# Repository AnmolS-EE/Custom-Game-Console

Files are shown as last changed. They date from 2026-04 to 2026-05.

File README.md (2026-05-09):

# Custom ESP32 Arcade Console (V1.0)

An arcade-style game console built around the ESP32 microcontroller featuring a custom 2-layer PCB, OLED display, joystick input, tactile buttons, buzzer feedback, and multi-color LED's.

## Hardware Features
* **Microcontroller:** ESP32-WROOM-32
* **Display:** 0.96" I2C OLED Display
* **Controls:** 2-axis analog joystick + 4 tactile push buttons
* **Feedback:** Active buzzer for game audio + 4 status LEDs
* **Power:** Custom 2-layer PCB designed in KiCad

### Schematic
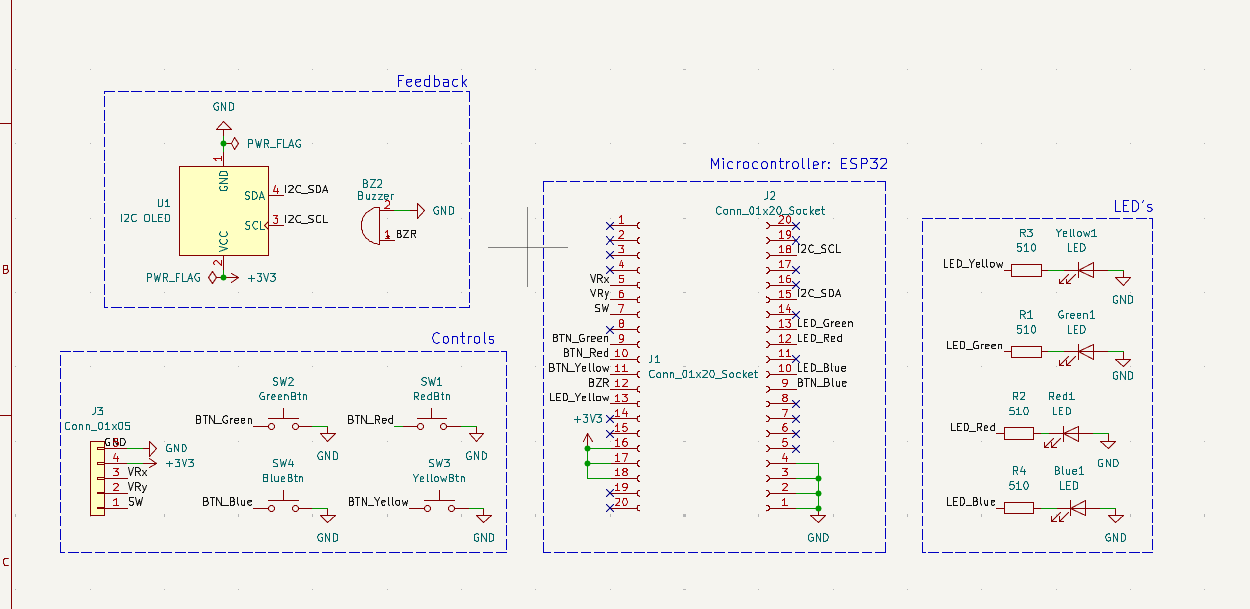
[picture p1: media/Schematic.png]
Circuit Schematic


### 3D PCB View
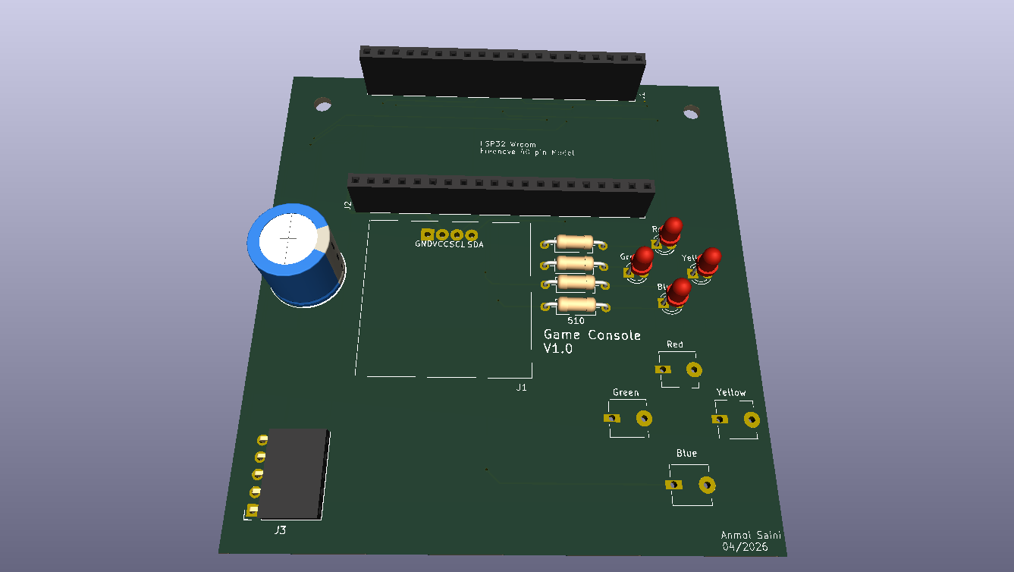
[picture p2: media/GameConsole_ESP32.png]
3D PCB View


## Project Evolution: Breadboard to PCB
The project began as a fully functional breadboard prototype used to validate:

* GPIO pin mapping
* joystick input behavior
* display communication (I2C)
* game state transitions
* buzzer and LED feedback logic

### Breadboard Prototype
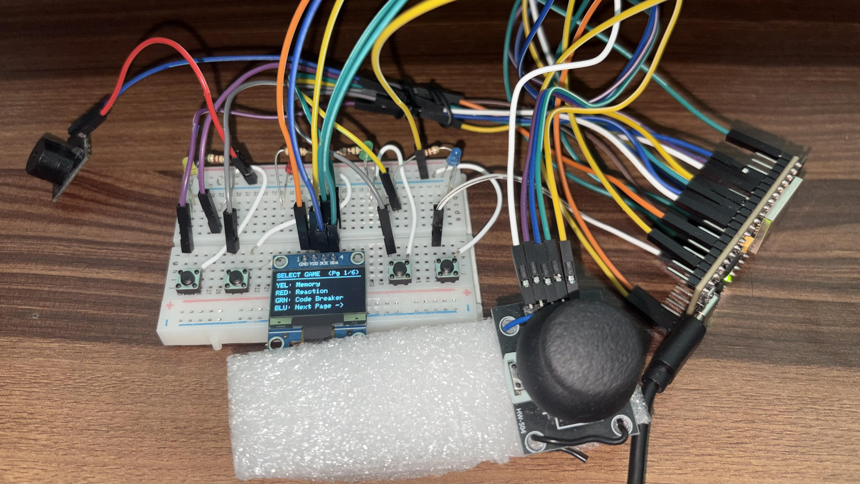
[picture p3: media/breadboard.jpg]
Breadboard Prototype
]

After successful testing, the system was transferred to a custom PCB designed in KiCad, focusing on clean signal routing, reliable power delivery, and compact system integration. 

### Assembled Hardware
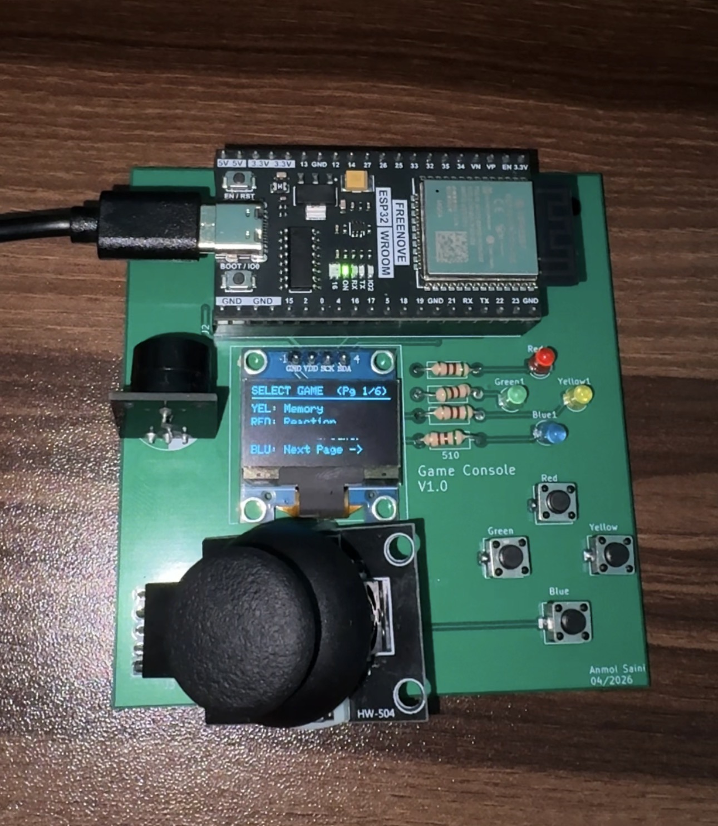
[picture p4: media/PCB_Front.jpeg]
Fully Assembled PCB


The final manufactured board has been created and the components have been soldered on. This transformed the initial breadboard concept into a robust, standalone device. You can watch a small edit of the soldering and final assembly process in my [TikTok build video](https://www.tiktok.com/@anmol.ee/video/7637941595454639381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).

## Firmware & Logic
Firmware was developed using C++ (Arduino IDE) on the ESP32 development board.
The software architecture supports multiple programmable games with modular input handling, display rendering, state management, and sound feedback.

## Future Improvements (V2.0)
While version 1.0 successfully validates the core hardware and software architecture, future versions will focus on a more clean and consumer-ready design. Planned improvements include:

* **Component Integration:** Transitioning away from bulky pre-packaged modules by designing custom footprints to mount a bare joystick and buzzer directly onto the PCB.
* **Enhanced Display:** Upgrading to a larger OLED screen for improved visibility and addition of color.
* **Layout Optimization:** Refining the PCB trace routing and component placement for an even cleaner and more efficient board design.
* **Custom Enclosure:** Designing and 3D printing a custom case to house the console, improve handling, and protect the exposed circuitry.

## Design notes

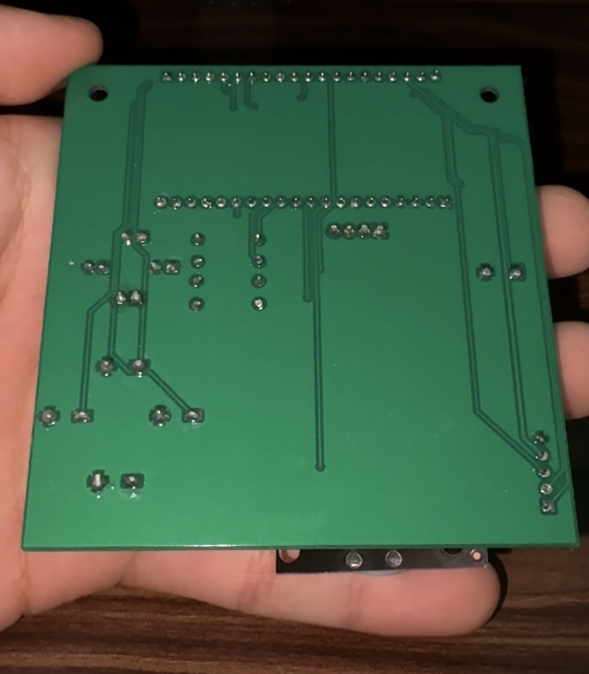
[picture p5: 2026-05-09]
media/PCB_Back.jpeg

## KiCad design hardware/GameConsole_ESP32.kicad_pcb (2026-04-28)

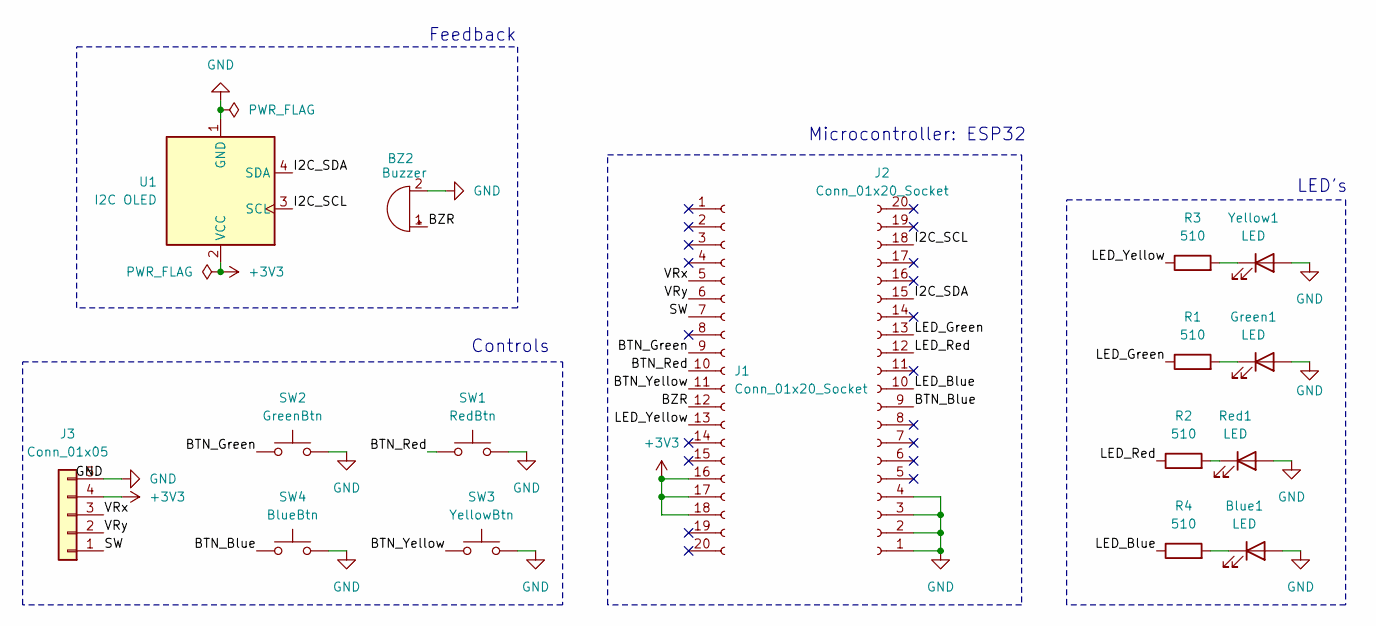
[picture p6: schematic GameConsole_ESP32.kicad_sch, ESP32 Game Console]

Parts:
BZ2: Buzzer; CP_Radial_D12.5mm_P5.00mm
Blue1: LED; LED_D3.0mm
Green1: LED; LED_D3.0mm
J1, J2: Conn_01x20_Socket; PinSocket_1x20_P2.54mm_Vertical
J3: Conn_01x05; PinSocket_1x05_P2.54mm_Horizontal
R1, R2, R3, R4: 510; R_Axial_DIN0207_L6.3mm_D2.5mm_P10.16mm_Horizontal
Red1: LED; LED_D3.0mm
SW1: RedBtn; SW_PUSH_6x6mm_2Pin_P5.08mm
SW2: GreenBtn; SW_PUSH_6x6mm_2Pin_P5.08mm
SW3: YellowBtn; SW_PUSH_6x6mm_2Pin_P5.08mm
SW4: BlueBtn; SW_PUSH_6x6mm_2Pin_P5.08mm
U1: I2C OLED; miniOLED
Yellow1: LED; LED_D3.0mm

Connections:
+3V3: J1.16, J1.17, J1.18, J3.4, U1.2 (VCC)
/BTN_Blue: J2.9, SW4.1
/BTN_Green: J1.9, SW2.1
/BTN_Red: J1.10, SW1.1
/BTN_Yellow: J1.11, SW3.1
/BZR: BZ2.1 (+), J1.12
/I2C_SCL: J2.18, U1.3 (SCL)
/I2C_SDA: J2.15, U1.4 (SDA)
/LED_Blue: J2.10, R4.1
/LED_Green: J2.13, R1.1
/LED_Red: J2.12, R2.1
/LED_Yellow: J1.13, R3.1
/SW: J1.7, J3.1
/VRx: J1.5, J3.3
/VRy: J1.6, J3.2
GND: BZ2.2 (-), Blue1.2 (A), Green1.2 (A), J2.1, J2.2, J2.3, J2.4, J3.5, Red1.2 (A), SW1.2, SW2.2, SW3.2, SW4.2, U1.1 (GND), Yellow1.2 (A)
unnamed: Blue1.1 (K), R4.2
unnamed: Green1.1 (K), R1.2
unnamed: R2.2, Red1.1 (K)
unnamed: R3.2, Yellow1.1 (K)

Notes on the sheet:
Microcontroller: ESP32
LED's
Controls
Feedback

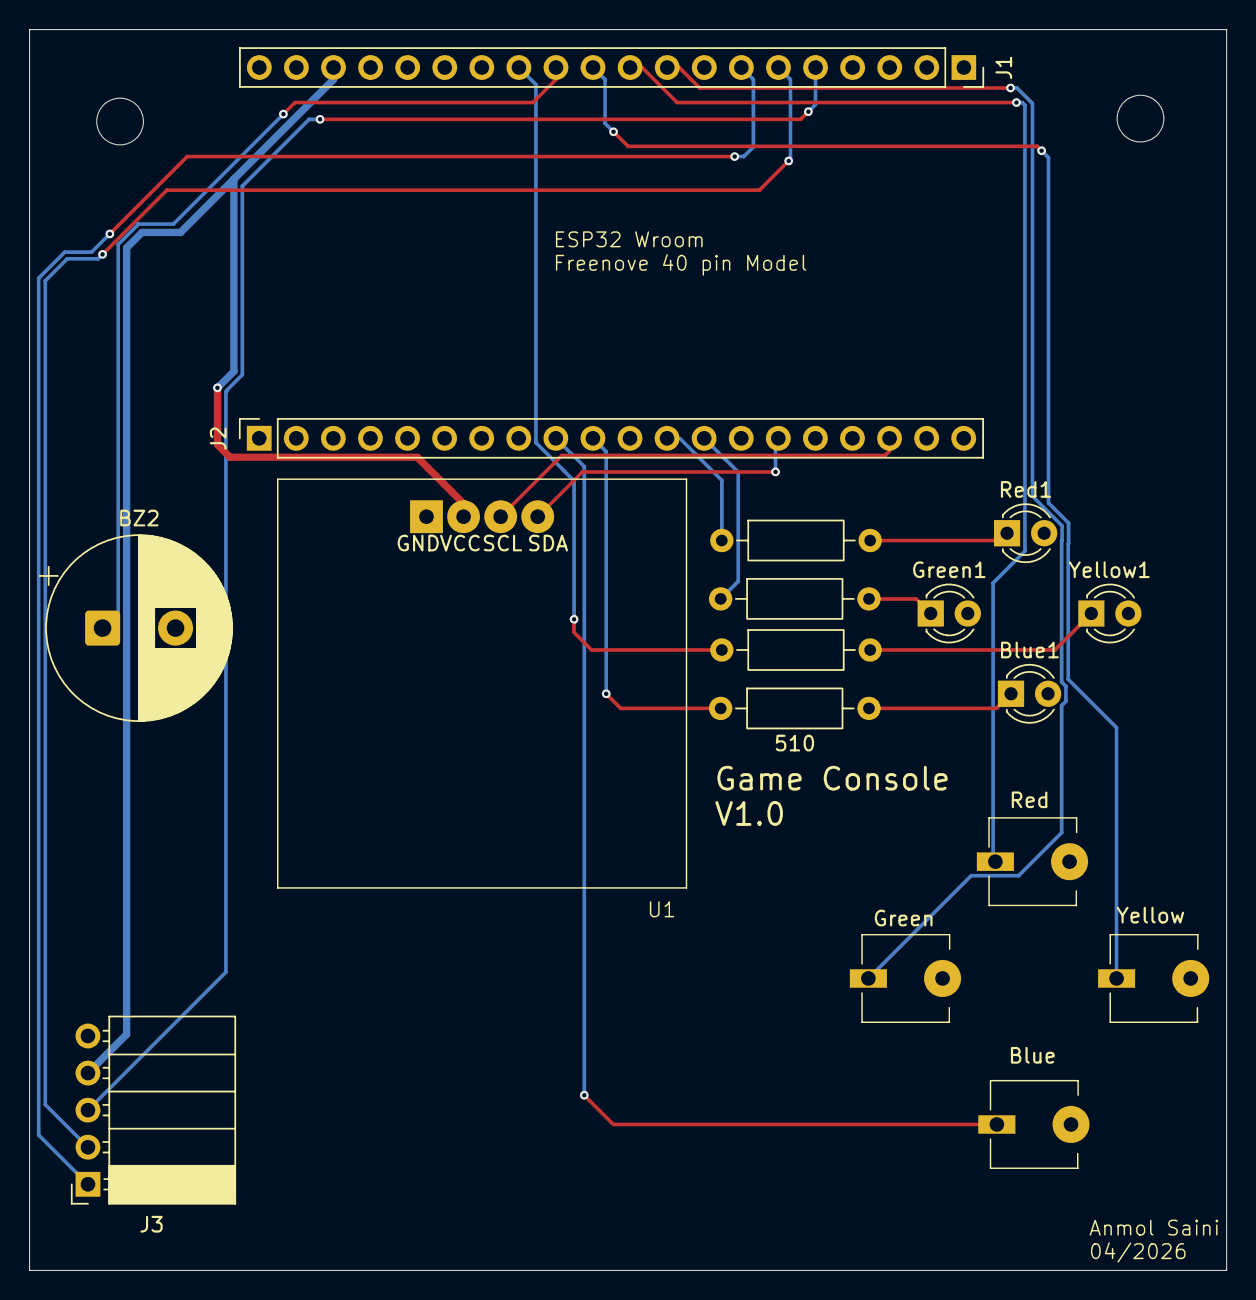
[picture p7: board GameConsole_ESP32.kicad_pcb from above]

Board: 2 copper layers, 82.0 x 85.0 mm, 17 parts (0 on the bottom side), 20 nets.

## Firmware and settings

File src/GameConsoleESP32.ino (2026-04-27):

#include <Wire.h>
#include <Adafruit_GFX.h>
#include <Adafruit_SSD1306.h>
#include <Preferences.h>

#define SCREEN_WIDTH 128 
#define SCREEN_HEIGHT 64 
Adafruit_SSD1306 display(SCREEN_WIDTH, SCREEN_HEIGHT, &Wire, -1);


Preferences preferences;


int leds[] = {13, 18, 19, 17};   // 0:Yellow, 1:Red, 2:Green, 3:Blue
int btns[] = {27, 26, 25, 16};   // Coressponding buttons
int buzzer = 14;              

// Game State Machine
enum GameState {
  MENU,
  MEM_START, REACT_START, CODE_START, CATCH_START, 
  LIGHTS_START, CIRCUIT_START, TWENTYONE_START,
  TRADER_START, DINO_START, WHACK_START, LUNAR_START, 
  SNAKE_START, MAZE_START, ASTEROID_START, SKY_START, CAVE_START
};
GameState currentState = MENU;

// Menu Pagination
int menuPage = 0; // 0 = Pg 1, 1 = Pg 2, 2 = Pg 3, 3 = Pg 4, 4 = Pg 5

// Global Game Variables
int gameSequence[50];            
int level = 2;                   

void setup() {
  Serial.begin(115200);
  if(!display.begin(SSD1306_SWITCHCAPVCC, 0x3C)) { for(;;); }

  for(int i=0; i<4; i++) {
    pinMode(leds[i], OUTPUT);
    pinMode(btns[i], INPUT_PULLUP);
  }
  pinMode(buzzer, OUTPUT);
  digitalWrite(buzzer, LOW);
  randomSeed(analogRead(0));
}

void loop() {
  switch (currentState) {
    case MENU: {
      showMenu();
      int btnPressed = waitForButton();
      
      if (btnPressed == 3) { // Blue button scrolls pages
        menuPage++;
        if (menuPage > 5) menuPage = 0;
        delay(200); 
      }
      else if (menuPage == 0) {
        if (btnPressed == 0) currentState = MEM_START;
        else if (btnPressed == 1) currentState = REACT_START;
        else if (btnPressed == 2) currentState = CODE_START;
      }
      else if (menuPage == 1) {
        if (btnPressed == 0) currentState = CATCH_START;
        else if (btnPressed == 1) currentState = LIGHTS_START;
        else if (btnPressed == 2) currentState = CIRCUIT_START;
      }
      else if (menuPage == 2) {
        if (btnPressed == 0) currentState = TWENTYONE_START;
        else if (btnPressed == 1) currentState = TRADER_START;
        else if (btnPressed == 2) currentState = DINO_START;
      }
      else if (menuPage == 3) {
        if (btnPressed == 0) currentState = WHACK_START;
        else if (btnPressed == 1) currentState = LUNAR_START; 
        else if (btnPressed == 2) currentState = SNAKE_START;
      }
      else if (menuPage == 4) {
        if (btnPressed == 0) currentState = MAZE_START;
        else if (btnPressed == 1) currentState = ASTEROID_START;
        else if (btnPressed == 2) currentState = SKY_START;
      }
      else if (menuPage == 5) {
        if (btnPressed == 0) currentState = CAVE_START;
      }
      break;
    }

    case MEM_START:
      showGameIntro("MEMORY GAME", "YELLOW");
      if (waitForButton() == 0) playMemoryGame();
      currentState = MENU; break;

    case REACT_START:
      showGameIntro("REACTION GAME", "RED");
      if (waitForButton() == 1) playReactionGame();
      currentState = MENU; break;

    case CODE_START:
      showGameIntro("CODE BREAKER", "GREEN");
      if (waitForButton() == 2) playCodeBreaker();
      currentState = MENU; break;

    case CATCH_START:
      showGameIntro("CATCH THE DOT", "YELLOW"); 
      if (waitForButton() == 0) playCatchGame();
      currentState = MENU; break;

    case LIGHTS_START:
      showGameIntro("LIGHTS OUT", "RED");
      if (waitForButton() == 1) playLightsOut();
      currentState = MENU; break;

    case CIRCUIT_START:
      showGameIntro("CIRCUIT CONNECT", "GREEN");
      if (waitForButton() == 2) playCircuitConnector();
      currentState = MENU; break;

    case TWENTYONE_START:
      showGameIntro("GAME OF 21", "YELLOW");
      if (waitForButton() == 0) playGameOf21();
      currentState = MENU; break;
      
    case TRADER_START:
      showGameIntro("DAY TRADER", "RED");
      if (waitForButton() == 1) playDayTrader();
      currentState = MENU; break;

    case DINO_START:
      showGameIntro("DINO RUN", "GREEN");
      if (waitForButton() == 2) playDinoRun();
      currentState = MENU; break;
      
    case WHACK_START:
      showGameIntro("WHACK A MOLE", "YELLOW");
      if (waitForButton() == 0) playWhackAMole();
      currentState = MENU; break;

    case LUNAR_START:
      showGameIntro("LUNAR LANDER", "RED");
      if (waitForButton() == 1) playLunarLander();
      currentState = MENU; break;
    
    case SNAKE_START:
      showGameIntro("CLASSIC SNAKE", "GREEN");
      if (waitForButton() == 2) playSnake();
      currentState = MENU; break;

    case MAZE_START:
      showGameIntro("SHADOW MAZE", "YELLOW");
      if (waitForButton() == 0) playShadowMaze();
      currentState = MENU; break;
    
    case ASTEROID_START:
      showGameIntro("ASTEROID DEF", "RED");
      if (waitForButton() == 1) playAsteroidDefender();
      currentState = MENU; break;

    case SKY_START:
      showGameIntro("SKY DEFENDER", "GREEN");
      if (waitForButton() == 2) playSkyDefender();
      currentState = MENU; break;
    
    case CAVE_START:
      showGameIntro("CAVE FLYER", "YELLOW");
      if (waitForButton() == 0) playCaveFlyer();
      currentState = MENU; break;
  }
}

// --- UI DISPLAY FUNCTIONS ---

void showMenu() {
  display.clearDisplay();
  display.setTextSize(1);
  display.setTextColor(WHITE);
  
  display.setCursor(0, 0);
  display.print("SELECT GAME  (Pg "); display.print(menuPage + 1); display.println("/6)");
  display.drawLine(0, 10, 128, 10, WHITE);
  
  if (menuPage == 0) {
    display.setCursor(0, 16); display.println("YEL: Memory");
    display.setCursor(0, 28); display.println("RED: Reaction");
    display.setCursor(0, 40); display.println("GRN: Code Breaker");
  } else if (menuPage == 1) {
    display.setCursor(0, 16); display.println("YEL: Catch the Dot");
    display.setCursor(0, 28); display.println("RED: Lights Out");
    display.setCursor(0, 40); display.println("GRN: Circuit Connect");
  } else if (menuPage == 2) {
    display.setCursor(0, 16); display.println("YEL: Game of 21");
    display.setCursor(0, 28); display.println("RED: Day Trader");
    display.setCursor(0, 40); display.println("GRN: Dino Run");
  } else if (menuPage == 3) {
    display.setCursor(0, 16); display.println("YEL: Whack-a-Mole");
    display.setCursor(0, 28); display.println("RED: Lunar Lander");
    display.setCursor(0, 40); display.println("GRN: Snake");
  } else if (menuPage == 4) {
    display.setCursor(0, 16); display.println("YEL: Shadow Maze");
    display.setCursor(0, 28); display.println("RED: Asteroid Def"); 
    display.setCursor(0, 40); display.println("GRN: Sky Defender");
  } else if (menuPage == 5) {
    display.setCursor(0, 16); display.println("YEL: Cave Flyer");
    display.setCursor(0, 28); display.println("RED: ---");
    display.setCursor(0, 40); display.println("GRN: ---");
  }
  
  display.setCursor(0, 52); display.println("BLU: Next Page ->");
  display.display();
}

void showGameIntro(String title, String buttonColor) {
  display.clearDisplay();
  display.setTextSize(1);
  display.setCursor(0, 10); display.println(title);
  display.setCursor(0, 35);
  display.print("Press "); display.print(buttonColor); display.println(" again");
  display.println("to Start!");
  display.display();
}

void countdown() {
  for (int i = 3; i > 0; i--) {
    display.clearDisplay();
    display.setTextSize(4); display.setCursor(50, 20); display.println(i);
    display.display();
    digitalWrite(buzzer, HIGH); delay(100); digitalWrite(buzzer, LOW); delay(900); 
  }
  display.clearDisplay(); display.setCursor(30, 20); display.println("GO!");
  display.display(); delay(500);
}

// --- HARDWARE HELPER FUNCTIONS ---

void flashLED(int index) {
  digitalWrite(leds[index], HIGH);
  digitalWrite(buzzer, HIGH); delay(200);
  digitalWrite(leds[index], LOW);
  digitalWrite(buzzer, LOW);
}

int waitForButton() {
  while (true) {
    for (int i = 0; i < 4; i++) {
      if (digitalRead(btns[i]) == LOW) {
        delay(50); // Debounce
        while(digitalRead(btns[i]) == LOW); // Wait for release
        return i;
      }
    }
  }
}

void LEDMultiflash() {
  for (int count = 0; count < 7; count++) { 
    for (int i = 0; i < 4; i++) digitalWrite(leds[i], HIGH);
    delay(150);
    for (int i = 0; i < 4; i++) digitalWrite(leds[i], LOW);
    delay(150);
  }
}

// --- GAME 1: MEMORY (SIMON) ---
void playMemoryGame() {
  preferences.begin("scores", false);
  int best = preferences.getInt("mem", 0);

  level = 2; 
  bool isAlive = true;
  countdown();
  while (isAlive) {
    display.clearDisplay(); display.setCursor(20, 25); display.setTextSize(2);
    display.print("LEVEL: "); display.println(level); display.display();
    delay(1000);

    for (int i = 0; i < level; i++) gameSequence[i] = random(0, 4);
    for (int i = 0; i < level; i++) { flashLED(gameSequence[i]); delay(200); }
    for (int i = 0; i < level; i++) {
      int expected = gameSequence[i];
      int pressed = waitForButton();
      if (pressed != expected) { isAlive = false; break; }
      flashLED(pressed); 
    }
    if (isAlive) { level++; delay(500); }
  }
  
  int finalScore = level - 1;
  bool newRecord = false;
  if (finalScore > best) {
    best = finalScore;
    preferences.putInt("mem", best);
    newRecord = true;
  }
  preferences.end();

  display.clearDisplay(); display.setTextSize(2); 
  if (newRecord) {
    display.setCursor(5, 10); display.println("NEW RECORD");
  } else {
    display.setCursor(10, 10); display.println("LOSER");
  }
  display.setTextSize(1); 
  display.setCursor(0, 35); display.print("Score: "); display.println(finalScore);
  display.setCursor(0, 48); display.print("Best:  "); display.println(best);
  display.display();

  digitalWrite(buzzer, HIGH); LEDMultiflash(); digitalWrite(buzzer, LOW); delay(3000); 
}

// --- GAME 2: REACTION ---
void playReactionGame() {
  preferences.begin("scores", false);
  int best = preferences.getInt("react", 99999);

  countdown();
  unsigned long totalTime = 0;
  for(int trial = 1; trial <= 3; trial++) {
    display.clearDisplay(); display.setTextSize(2); display.setCursor(10, 20);
    display.print("TRIAL "); display.println(trial); display.setTextSize(1);
    display.setCursor(0, 45); display.println("Wait for it..."); display.display();

    delay(random(1500, 5000));
    int target = random(0, 4);
    digitalWrite(leds[target], HIGH);
    
    unsigned long startTime = millis();
    int pressed = -1;
    while(pressed != target) { pressed = waitForButton(); }
    
    unsigned long reactionTime = millis() - startTime;
    digitalWrite(leds[target], LOW);
    totalTime += reactionTime;

    display.clearDisplay(); display.setTextSize(2); display.setCursor(10, 20);
    display.print(reactionTime); display.println(" ms"); display.display(); delay(2000);
  }

  int avg = totalTime / 3;
  bool newRecord = false;
  if (avg < best) {
    best = avg;
    preferences.putInt("react", best);
    newRecord = true;
  }
  preferences.end();

  display.clearDisplay(); display.setTextSize(2); 
  if (newRecord) {
    display.setCursor(5, 10); display.println("NEW RECORD");
  } else {
    display.setCursor(20, 10); display.println("AVERAGE");
  }
  display.setTextSize(1); 
  display.setCursor(0, 35); display.print("Avg:  "); display.print(avg); display.println("ms");
  display.setCursor(0, 48); display.print("Best: "); display.print(best); display.println("ms");
  display.display(); 
  
  if(newRecord) LEDMultiflash();
  delay(5000);
}

// --- GAME 3: CODE BREAKER ---
void playCodeBreaker() {
  countdown();
  int secret[4];
  for(int i=0; i<4; i++) secret[i] = random(0, 4); 
  
  int attempts = 0; bool cracked = false;
  
  while(attempts < 10 && !cracked) {
    display.clearDisplay(); display.setTextSize(1); display.setCursor(0,0);
    display.print("Attempt "); display.print(attempts + 1); display.println("/10");
    display.drawLine(0, 10, 128, 10, WHITE); display.setCursor(0, 20);
    display.println("Input 4 colors:"); display.display();
    
    int guess[4]; display.setCursor(0, 35); display.setTextSize(2);
    for(int i=0; i<4; i++) {
      guess[i] = waitForButton(); flashLED(guess[i]);
      display.print("* "); display.display();
    }
    
    int exactMatch = 0; int colorMatch = 0;  
    bool secretUsed[4] = {false, false, false, false};
    bool guessUsed[4]  = {false, false, false, false};
    
    for(int i=0; i<4; i++) {
      if(guess[i] == secret[i]) { exactMatch++; secretUsed[i] = true; guessUsed[i] = true; }
    }
    for(int i=0; i<4; i++) {
      if(!guessUsed[i]) {
        for(int j=0; j<4; j++) {
          if(!secretUsed[j] && guess[i] == secret[j]) { colorMatch++; secretUsed[j] = true; break; }
        }
      }
    }
    
    display.clearDisplay(); display.setTextSize(1); display.setCursor(0, 0); 
    display.println("CLUES:"); display.drawLine(0, 10, 128, 10, WHITE);
    display.setCursor(0, 20); display.print("Perfect:     "); display.println(exactMatch);
    display.setCursor(0, 35); display.print("Wrong Spot:  "); display.println(colorMatch);
    display.display();
    
    if(exactMatch == 4) { cracked = true; break; }
    attempts++; delay(3500); 
  }
  display.clearDisplay(); display.setTextSize(2); display.setCursor(0, 15);
  if(cracked) { display.println("CRACKED!"); LEDMultiflash(); } 
  else { display.println("FAILED..."); }
  display.display(); delay(4000);
}

// --- GAME 4: CATCH THE DOT ---
void playCatchGame() {
  preferences.begin("scores", false);
  int best = preferences.getInt("catch", 0);

  countdown();
  unsigned long speed = 250; 
  int score = 0; bool isAlive = true;
  int currentPos = 0; int direction = 1; 
  String colorNames[] = {"YELLOW", "RED", "GREEN", "BLUE"};

  while(isAlive) {
    int target = random(0, 4); bool caught = false;
    
    display.clearDisplay(); display.setTextSize(2); display.setCursor(0, 0); 
    display.print("Sc: "); display.println(score); display.setTextSize(1);
    display.setCursor(0, 25); display.println("TARGET COLOR:"); display.setTextSize(2);
    display.setCursor(0, 40); display.println(colorNames[target]); display.display();
    
    while(!caught && isAlive) {
      digitalWrite(leds[currentPos], HIGH);
      unsigned long startMs = millis(); int pressedBtn = -1;
      
      while(millis() - startMs < speed) {
        for(int i=0; i<4; i++) {
          if(digitalRead(btns[i]) == LOW) { pressedBtn = i; delay(50); break; }
        }
        if(pressedBtn != -1) break; 
      }
      digitalWrite(leds[currentPos], LOW);
      
      if(pressedBtn != -1) {
         if(pressedBtn == target && currentPos == target) {
            digitalWrite(buzzer, HIGH); delay(100); digitalWrite(buzzer, LOW);
            score++; speed = speed - (speed / 10); caught = true;
            while(digitalRead(btns[pressedBtn]) == LOW);
         } else { isAlive = false; }
      }
      
      if(!caught && isAlive) {
        currentPos += direction;
        if(currentPos >= 3) { currentPos = 3; direction = -1; } 
        else if(currentPos <= 0) { currentPos = 0; direction = 1; }
      }
    }
  }

  bool newRecord = false;
  if (score > best) {
    best = score;
    preferences.putInt("catch", best);
    newRecord = true;
  }
  preferences.end();

  display.clearDisplay(); display.setTextSize(2); 
  if (newRecord) {
    display.setCursor(5, 10); display.println("NEW RECORD");
  } else {
    display.setCursor(10, 10); display.println("LOSER");
  }
  display.setTextSize(1); 
  display.setCursor(0, 35); display.print("Score: "); display.println(score);
  display.setCursor(0, 48); display.print("Best:  "); display.println(best);
  display.display();

  digitalWrite(buzzer, HIGH); LEDMultiflash(); digitalWrite(buzzer, LOW); delay(4000);
}

// --- GAME 5: LIGHTS OUT ---
void playLightsOut() {
  preferences.begin("scores", false);
  int best = preferences.getInt("lights", 9999);

  countdown();
  bool board[4] = {false, false, false, false};
  
  for(int i=0; i<5; i++) {
     int r = random(0, 4);
     board[r] = !board[r];
     if(r > 0) board[r-1] = !board[r-1];
     if(r < 3) board[r+1] = !board[r+1];
  }
  if(!board[0] && !board[1] && !board[2] && !board[3]) board[0] = true;

  bool playing = true;
  int moves = 0;
  
  while(playing) {
     for(int i=0; i<4; i++) digitalWrite(leds[i], board[i] ? HIGH : LOW);
     
     display.clearDisplay();
     display.setTextSize(2); display.setCursor(0,0); display.println("LIGHTS OUT");
     display.setTextSize(1); display.setCursor(0, 25); 
     display.println("Turn all LEDs OFF");
     display.setCursor(0, 45); display.print("Moves: "); display.println(moves);
     display.display();
     
     int btn = waitForButton();
     moves++;
     digitalWrite(buzzer, HIGH); delay(50); digitalWrite(buzzer, LOW);
     
     board[btn] = !board[btn];
     if(btn > 0) board[btn-1] = !board[btn-1];
     if(btn < 3) board[btn+1] = !board[btn+1];
     
     if(!board[0] && !board[1] && !board[2] && !board[3]) playing = false;
  }
  
  for(int i=0; i<4; i++) digitalWrite(leds[i], LOW);

  bool newRecord = false;
  if (moves < best) {
    best = moves;
    preferences.putInt("lights", best);
    newRecord = true;
  }
  preferences.end();

  display.clearDisplay(); display.setTextSize(2); 
  if (newRecord) {
    display.setCursor(5, 10); display.println("NEW RECORD");
  } else {
    display.setCursor(20, 10); display.println("SOLVED!");
  }
  display.setTextSize(1); 
  display.setCursor(0, 35); display.print("Moves: "); display.println(moves);
  display.setCursor(0, 48); display.print("Best:  "); display.println(best);
  display.display();
  
  LEDMultiflash(); delay(4000);
}

// --- GAME 6: CIRCUIT CONNECTOR ---
void playCircuitConnector() {
  countdown();
  bool isAlive = true;

  for (int level = 1; level <= 3; level++) {
    if (!isAlive) break;

    int tileTypes[4]; 
    int solution[4];  
    unsigned long timeLimit = 20000; 

    if (level == 1) {
      int t[] = {1, 0, 1, 0}; memcpy(tileTypes, t, sizeof(t));
      int s[] = {3, 1, 1, 0}; memcpy(solution, s, sizeof(s));
    } else if (level == 2) {
      int t[] = {0, 1, 0, 1}; memcpy(tileTypes, t, sizeof(t));
      int s[] = {0, 3, 1, 1}; memcpy(solution, s, sizeof(s)); 
      timeLimit = 15000;
    } else {
      int t[] = {1, 1, 1, 1}; memcpy(tileTypes, t, sizeof(t));
      int s[] = {3, 2, 1, 0}; memcpy(solution, s, sizeof(s));
      timeLimit = 12000;
    }

    int tiles[4];
    for (int i = 0; i < 4; i++) {
      tiles[i] = random(0, 4);
      if (tiles[i] == solution[i]) tiles[i] = (tiles[i] + 1) % 4; 
    }

    unsigned long startTime = millis();
    bool levelWon = false;

    while (millis() - startTime < timeLimit && !levelWon) {
      int timeLeft = (timeLimit - (millis() - startTime)) / 1000;

      int btn = -1;
      for (int i = 0; i < 4; i++) {
        if (digitalRead(btns[i]) == LOW) {
          btn = i;
          delay(50); 
          while (digitalRead(btns[i]) == LOW); 
          break;
        }
      }

      if (btn != -1) {
        tiles[btn] = (tiles[btn] + 1) % 4;
        digitalWrite(buzzer, HIGH); delay(30); digitalWrite(buzzer, LOW);
      }

      display.clearDisplay();
      display.setTextSize(1);
      display.setCursor(0, 0); display.print("Lvl: "); display.print(level);
      display.setCursor(70, 0); display.print("Time: "); display.print(timeLeft);

      display.drawRect(5, 16, 12, 32, WHITE);
      display.setCursor(8, 28); display.print("+");
      display.drawLine(17, 24, 40, 24, WHITE); 
      display.drawLine(17, 48, 40, 48, WHITE); 

      display.drawCircle(115, 36, 10, WHITE);
      display.drawRect(105, 30, 5, 12, WHITE);
      display.drawLine(80, 24, 105, 24, WHITE); 
      display.drawLine(80, 48, 105, 48, WHITE); 

      display.drawLine(56, 24, 64, 24, WHITE); 
      display.drawLine(56, 48, 64, 48, WHITE); 
      display.drawLine(48, 32, 48, 40, WHITE); 
      display.drawLine(72, 32, 72, 40, WHITE); 

      int tx[] = {40, 64, 40, 64};
      int ty[] = {16, 16, 40, 40};
      
      for (int i = 0; i < 4; i++) {
        display.drawRect(tx[i], ty[i], 16, 16, WHITE); 
        int cx = tx[i] + 8; 
        int cy = ty[i] + 8; 

        int type = tileTypes[i];
        int rot = tiles[i];

        if (type == 0) { 
          if (rot == 0 || rot == 2) display.drawLine(tx[i], cy, tx[i] + 16, cy, WHITE);
          else display.drawLine(cx, ty[i], cx, ty[i] + 16, WHITE);
        } else { 
          if (rot == 0) { display.drawLine(cx, cy, tx[i], cy, WHITE); display.drawLine(cx, cy, cx, ty[i], WHITE); }       
          else if (rot == 1) { display.drawLine(cx, cy, cx, ty[i], WHITE); display.drawLine(cx, cy, tx[i] + 16, cy, WHITE); } 
          else if (rot == 2) { display.drawLine(cx, cy, tx[i] + 16, cy, WHITE); display.drawLine(cx, cy, cx, ty[i] + 16, WHITE); } 
          else if (rot == 3) { display.drawLine(cx, cy, cx, ty[i] + 16, WHITE); display.drawLine(cx, cy, tx[i], cy, WHITE); } 
        }
      }
      display.display();

      bool winCheck = true;
      for (int i = 0; i < 4; i++) {
        if (tileTypes[i] == 0) {
          if (tiles[i] % 2 != solution[i] % 2) winCheck = false; 
        } else {
          if (tiles[i] != solution[i]) winCheck = false;
        }
      }

      if (winCheck) {
        levelWon = true;
        display.fillCircle(115, 36, 10, WHITE);
        display.display();
        
        digitalWrite(buzzer, HIGH);
        for(int j=0; j<4; j++) digitalWrite(leds[j], HIGH);
        delay(500);
        digitalWrite(buzzer, LOW);
        for(int j=0; j<4; j++) digitalWrite(leds[j], LOW);
        delay(1000);
      }
    } 

    if (!levelWon) isAlive = false; 
  } 

  display.clearDisplay();
  display.setTextSize(2);
  display.setCursor(10, 10);
  
  if (isAlive) {
    display.println("YOU WIN!");
    LEDMultiflash();
  } else {
    display.println("OUT OF TIME");
    digitalWrite(buzzer, HIGH); LEDMultiflash(); digitalWrite(buzzer, LOW);
  }
  
  display.display();
  delay(3000);
}
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

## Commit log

2026-04-27 Create .gitignore to manage ignored files
    Add a .gitignore file to exclude build files, KiCad backups, and OS-generated junk files.
2026-04-27 Initial V1.0 KiCad schematic and PCB layout
    [GameConsole_ESP32.kicad_pcb, GameConsole_ESP32.kicad_sch]
2026-04-27 Add initial ESP32 game firmware.
2026-04-27 Breadboard prototype photo.
2026-04-27 Add initial 3D PCB design.
2026-04-28 Cleaned up schematic and updated PCB design
    [GameConsole_ESP32.kicad_pcb, GameConsole_ESP32.kicad_sch]
2026-04-29 Enhance README with schematic and PCB views
    Added schematic and 3D PCB view images to README.
2026-05-09 Uploading fully assembled PCB.
2026-05-09 Update README with assembled hardware and future plans
    Added details about the assembled hardware and future improvements.
